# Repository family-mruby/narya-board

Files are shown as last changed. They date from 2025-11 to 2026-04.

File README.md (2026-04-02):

# Narya Board

A dual ESP32 development board featuring both ESP32-WROVER-IE and ESP32-S3-WROOM-1 modules on a single PCB.

## Overview

Narya Board is a versatile hardware platform that integrates two popular ESP32 variants, providing developers with flexibility for WiFi/Bluetooth applications, IoT prototyping, and embedded systems development.

## Features

- **Dual ESP32 Modules:**
  - ESP32-WROVER-IE (16MB Flash) - ESP32 classic with PSRAM
  - ESP32-S3-WROOM-1 (N16R8) - Latest ESP32-S3 with 16MB Flash and 8MB PSRAM
- **Video Output:** NTSC composite video output for retro gaming and multimedia applications
- **Audio Output:** Integrated audio output for sound and music playback
- **USB Host:** USB host interface for connecting peripherals
- **SD Card:** MicroSD card slot for external storage and data logging
- **GROVE Connector:** Standard GROVE connector for easy sensor and module integration
- **KiCad 9.0:** Designed with the latest KiCad EDA suite

## Hardware Specifications

## Block Diagram

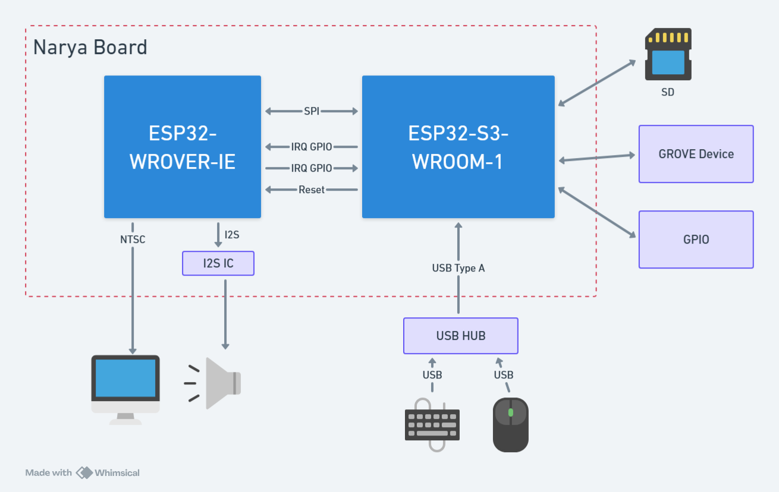
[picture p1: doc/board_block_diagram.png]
Block Diagram


### ESP32-WROVER-IE Module
- MCU: ESP32 Dual-core Xtensa LX6
- Flash: 16MB
- PSRAM: 8MB

### ESP32-S3-WROOM-1 Module
- MCU: ESP32-S3 Dual-core Xtensa LX7
- Flash: 16MB (N16)
- PSRAM: 8MB (R8)

## Project Structure

```
narya-board/
├── dev/
│   └── dev-board/              # Main KiCad project
│       ├── dev-board.kicad_pcb # PCB layout
│       ├── dev-board.kicad_sch # Main schematic
│       ├── dev-board.kicad_pro # KiCad project file
│       ├── S3_peripheral.kicad_sch        # ESP32-S3 peripheral circuits
│       ├── wrover_peripheral.kicad_sch   # WROVER peripheral circuits
│       ├── kicad/              # Custom libraries and footprints
│       └── production/         # Manufacturing files
│           ├── dev-board.zip   # Gerber files for fabrication
│           └── netlist.ipc     # IPC netlist
├── LICENSE
└── README.md
```

## History

### v3.0 dev R3

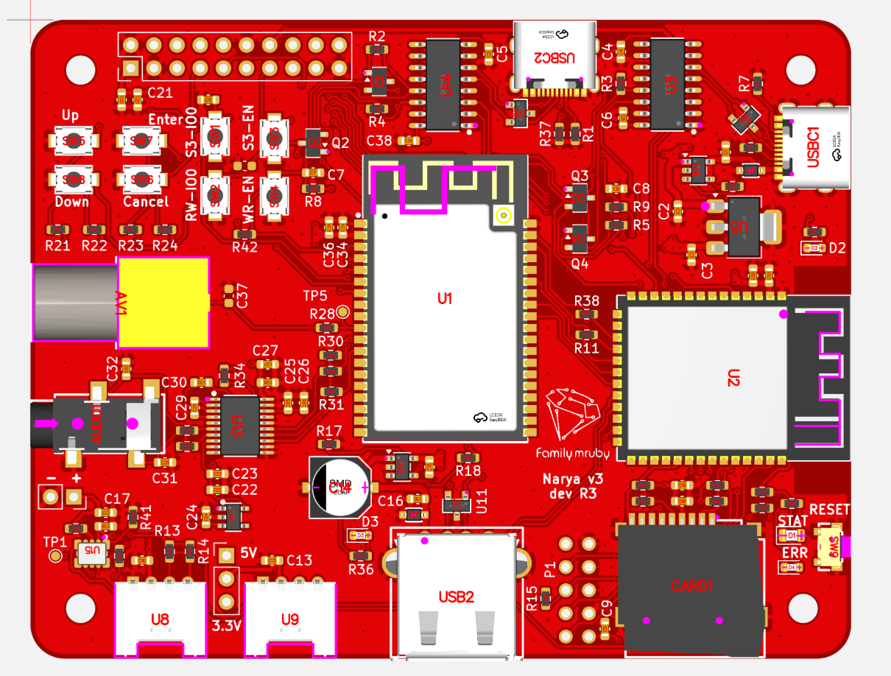
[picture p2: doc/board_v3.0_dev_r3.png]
3D Board View


## License

This project is licensed under the CERN-OHL-S - see the [LICENSE](LICENSE) file for details.

---

**Note:** This is a hardware development project. Ensure you have appropriate knowledge of electronics and safety precautions when working with these modules.

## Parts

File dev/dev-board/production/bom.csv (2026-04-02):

Designator | Footprint | Quantity | Value | LCSC Part #
AUDIO1 | AUDIO-SMD_PJ-327C-4A | 1 | PJ-327C-4A | C145813
AV1 | CONN-TH_AV-5 | 1 | AV-5 | C18080
C1, C10, C11, C13, C15, C16, C17, C18, C20, C23, C24, C25, C28, C33, C34, C38, C39, C4, C5, C6, C7, C8, C9 | 0603 | 23 | 0.1uF | C14663
C14 | CAP-SMD_BD6.3-L6.6-W6.6-LS7.2-R-RD | 1 | 120uF | C250087
C19, C2, C21, C22, C26, C27, C3 | 0603 | 7 | 10uF | C19702
C29, C30 | 0603 | 2 | 2.2uF | C23630
C31, C32 | 0603 | 2 | 2.2nF | C1604
C35, C36 | 0603 | 2 | 22uF | C84419
CARD1 | TF-SMD_TF-PUSH | 1 | TF PUSH | C393941
D1 | 0805 | 1 | LED GREEN | C2297
D2, D3, D4 | 0603 | 3 | LED RED | C2286
LDO1 | SOT-23-5_L3.0-W1.7-P0.95-LS2.8-BL | 1 | ME6211C33M5G-N | C82942
Q1, Q2, Q3, Q4 | SOT-23 | 4 | BSS138 | C82045
R1, R37, R6, R7 | 0603 | 4 | 5.1K | C23186
R10, R11, R12, R13, R14, R17, R18, R2, R20, R21, R22, R23, R24, R25, R26, R3, R34, R38, R4, R5, R8, R9 | 0603 | 22 | 10K | C25804
R15, R39, R40, R41, R42 | 0603 | 5 | 0 | C21189
R16, R19, R35, R36 | 0603 | 4 | 2K | C22975
R27, R28, R30, R31, R32 | 0603 | 5 | 22 | C23345
R29, R33 | 0603 | 2 | 470 | C23179
SW1, SW2, SW3, SW4, SW5, SW6, SW7, SW8 | KEY-SMD_L3.9-W3.0-LS5.0 | 8 | TS342A2P | C5373431
SW9 | SW-SMD_L4.7-W3.5-P3.35-EH | 1 | GT-TC018A-H0375-L1 | C963235
U1 | WIFI-SMD_ESP32-WROVER-IE8MB | 1 | ESP32-WROVER-IE(16MB) | C701352
U10, U4 | SOT-23-5 | 2 | TPS2065CDBV | C353882
U11, U16, U6 | SOT-23-3_L2.9-W1.3-P1.90-LS2.4-BR | 3 | PESD5V0U2BT | C2905622
U12, U7 | SOD-323_L1.7-W1.3-LS2.5-BI | 2 | PESD5V0S1BA_C5261083 | C5261083
U13 | TSSOP-20_L6.5-W4.4-P0.65-LS6.4-BL | 1 | PCM5102APWR | C107671
U14, U3 | SOP-16_L10.0-W3.9-P1.27-LS6.0-BL | 2 | CH340C | C84681
U15 | SMD-10_L3.2-W2.5-BL_EPSON_RX8900CE | 1 | RX8900CE_UB0 | C5903517
U2 | WIRELM-SMD_ESP32-S3-WROOM-1 | 1 | ESP32-S3-WROOM-1(N16R8) | C2913202
U5 | SOT-223-3_TabPin2 | 1 | AP7361C-33E | C150719
U8, U9 | CONN-TH_4P-P2.00_ZX-HY2.0-4PWZ | 2 | ZX-HY2.0-4PWZ | C7429589
USB2 | USB-A-TH_USB-231-ARY | 1 | USB-231-ARY | C720525
USBC1, USBC2 | USB-C_SMD-TYPE-C-31-M-12_1_Small | 2 | TYPE-C-31-M-12 | C165948

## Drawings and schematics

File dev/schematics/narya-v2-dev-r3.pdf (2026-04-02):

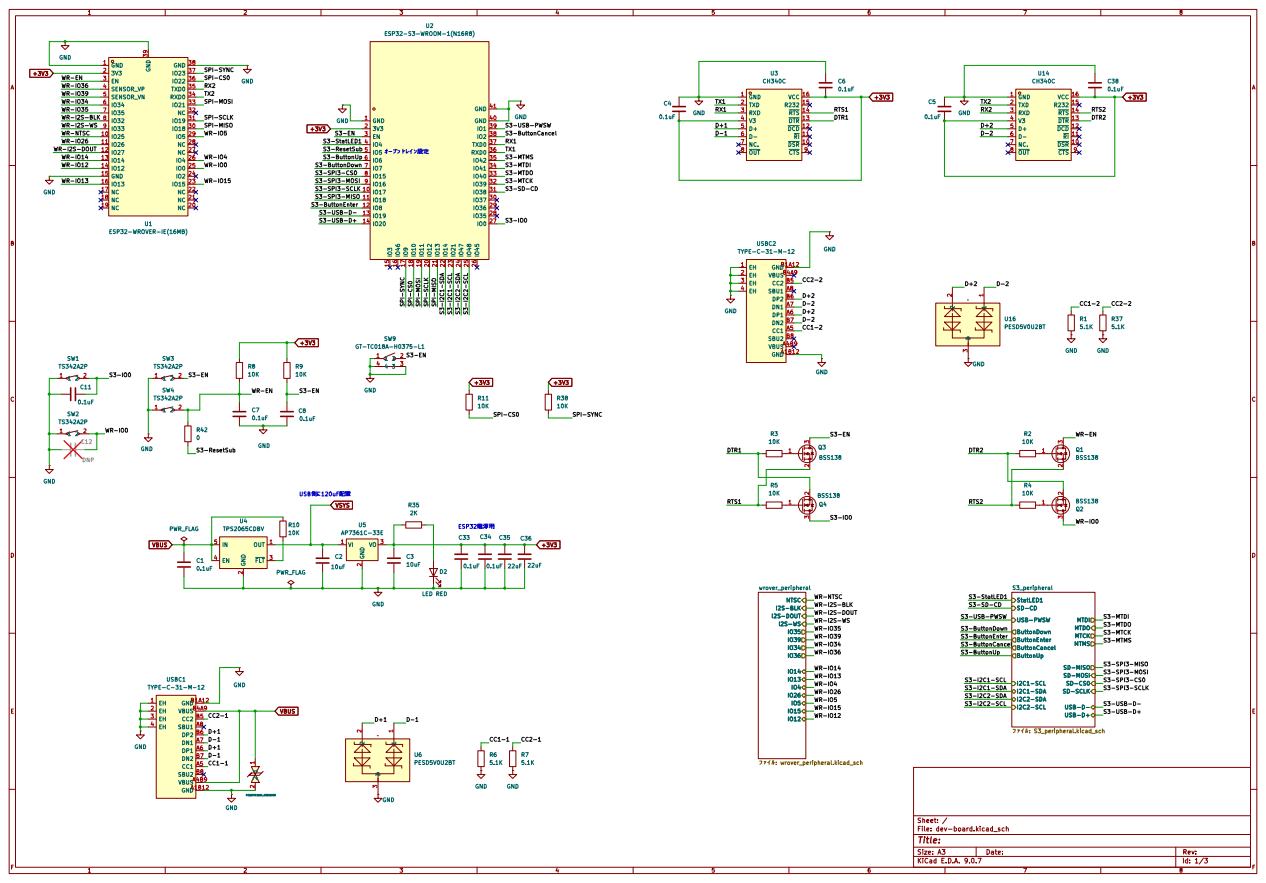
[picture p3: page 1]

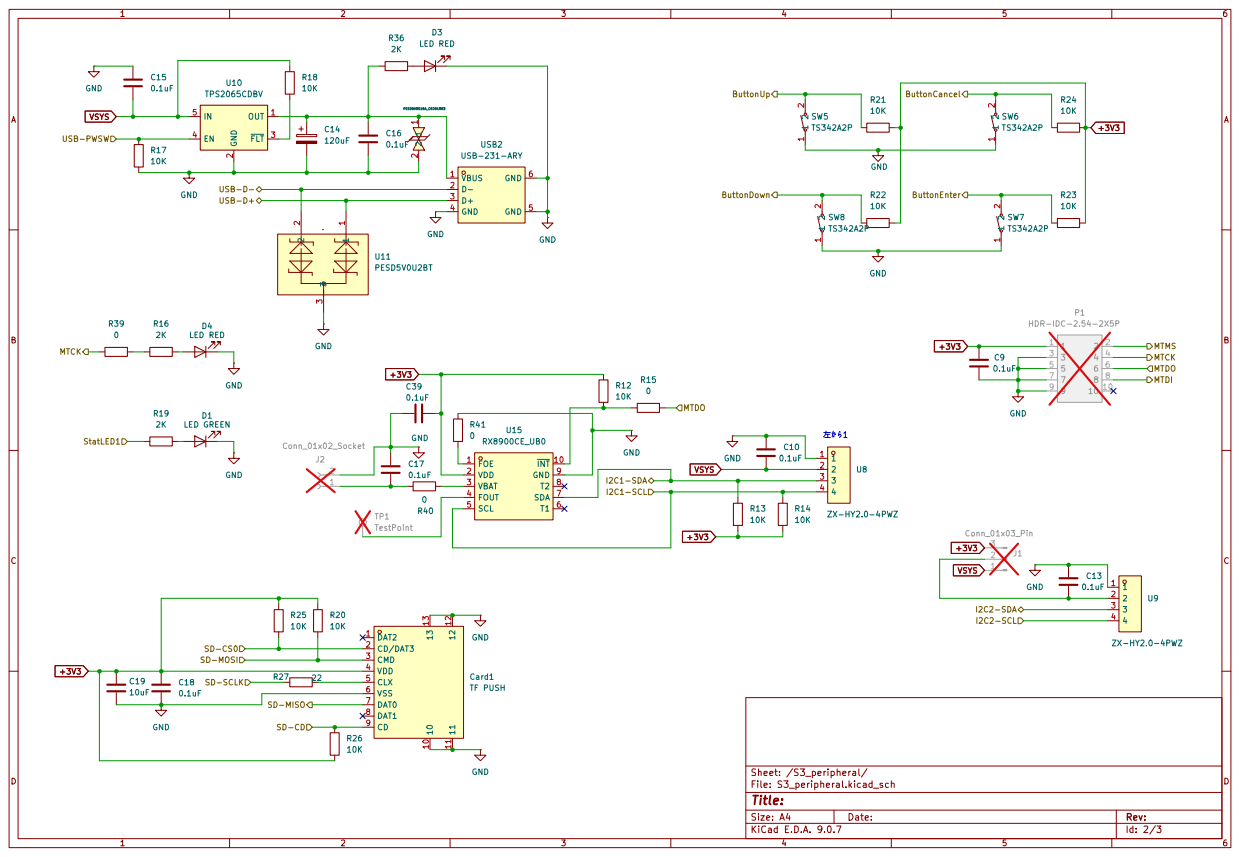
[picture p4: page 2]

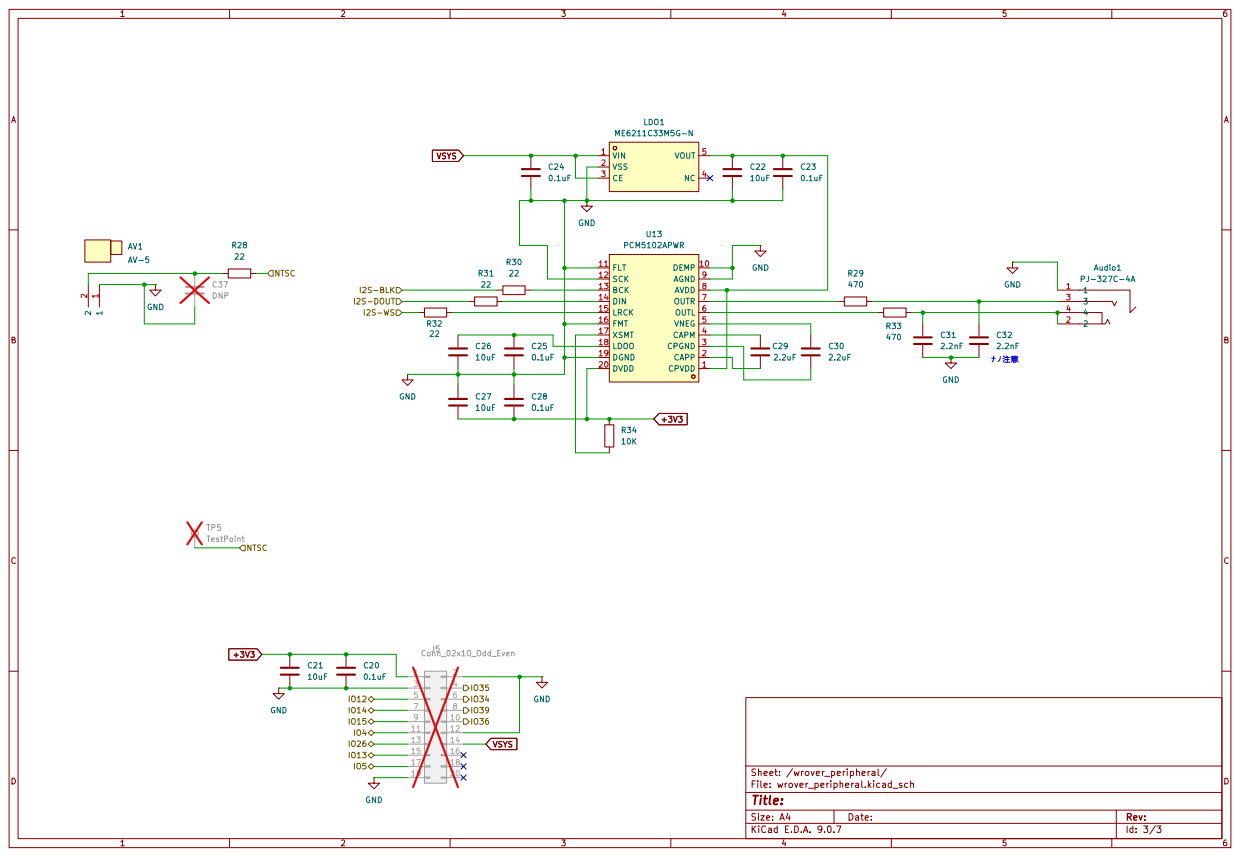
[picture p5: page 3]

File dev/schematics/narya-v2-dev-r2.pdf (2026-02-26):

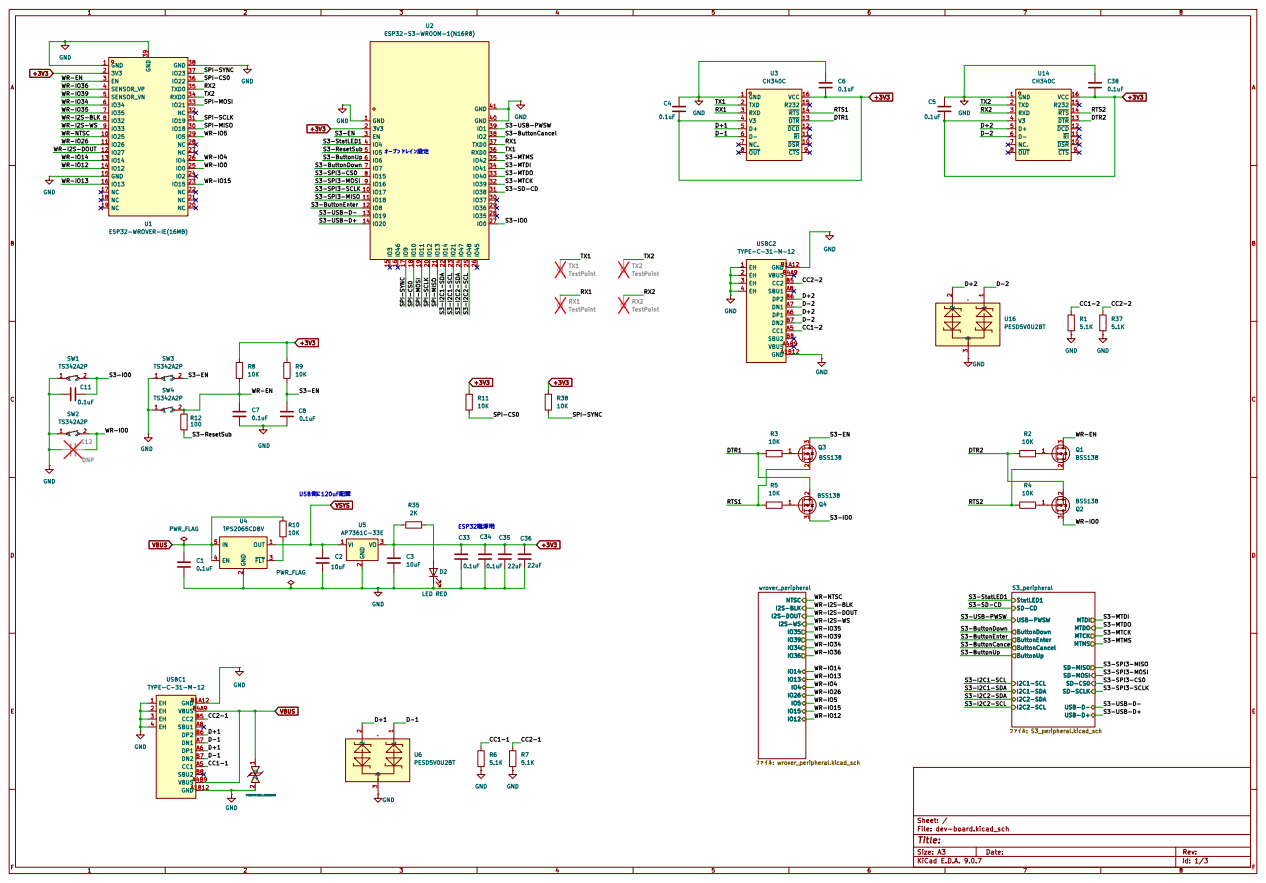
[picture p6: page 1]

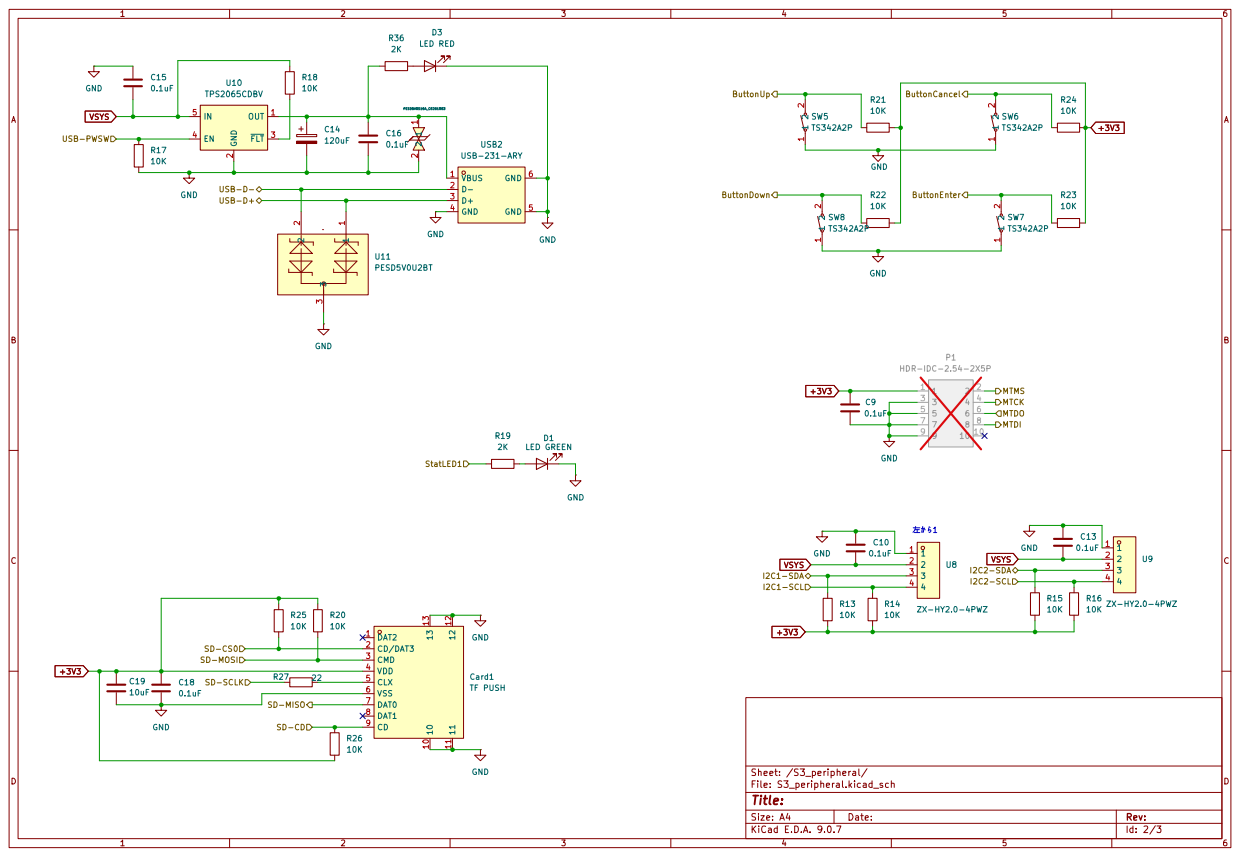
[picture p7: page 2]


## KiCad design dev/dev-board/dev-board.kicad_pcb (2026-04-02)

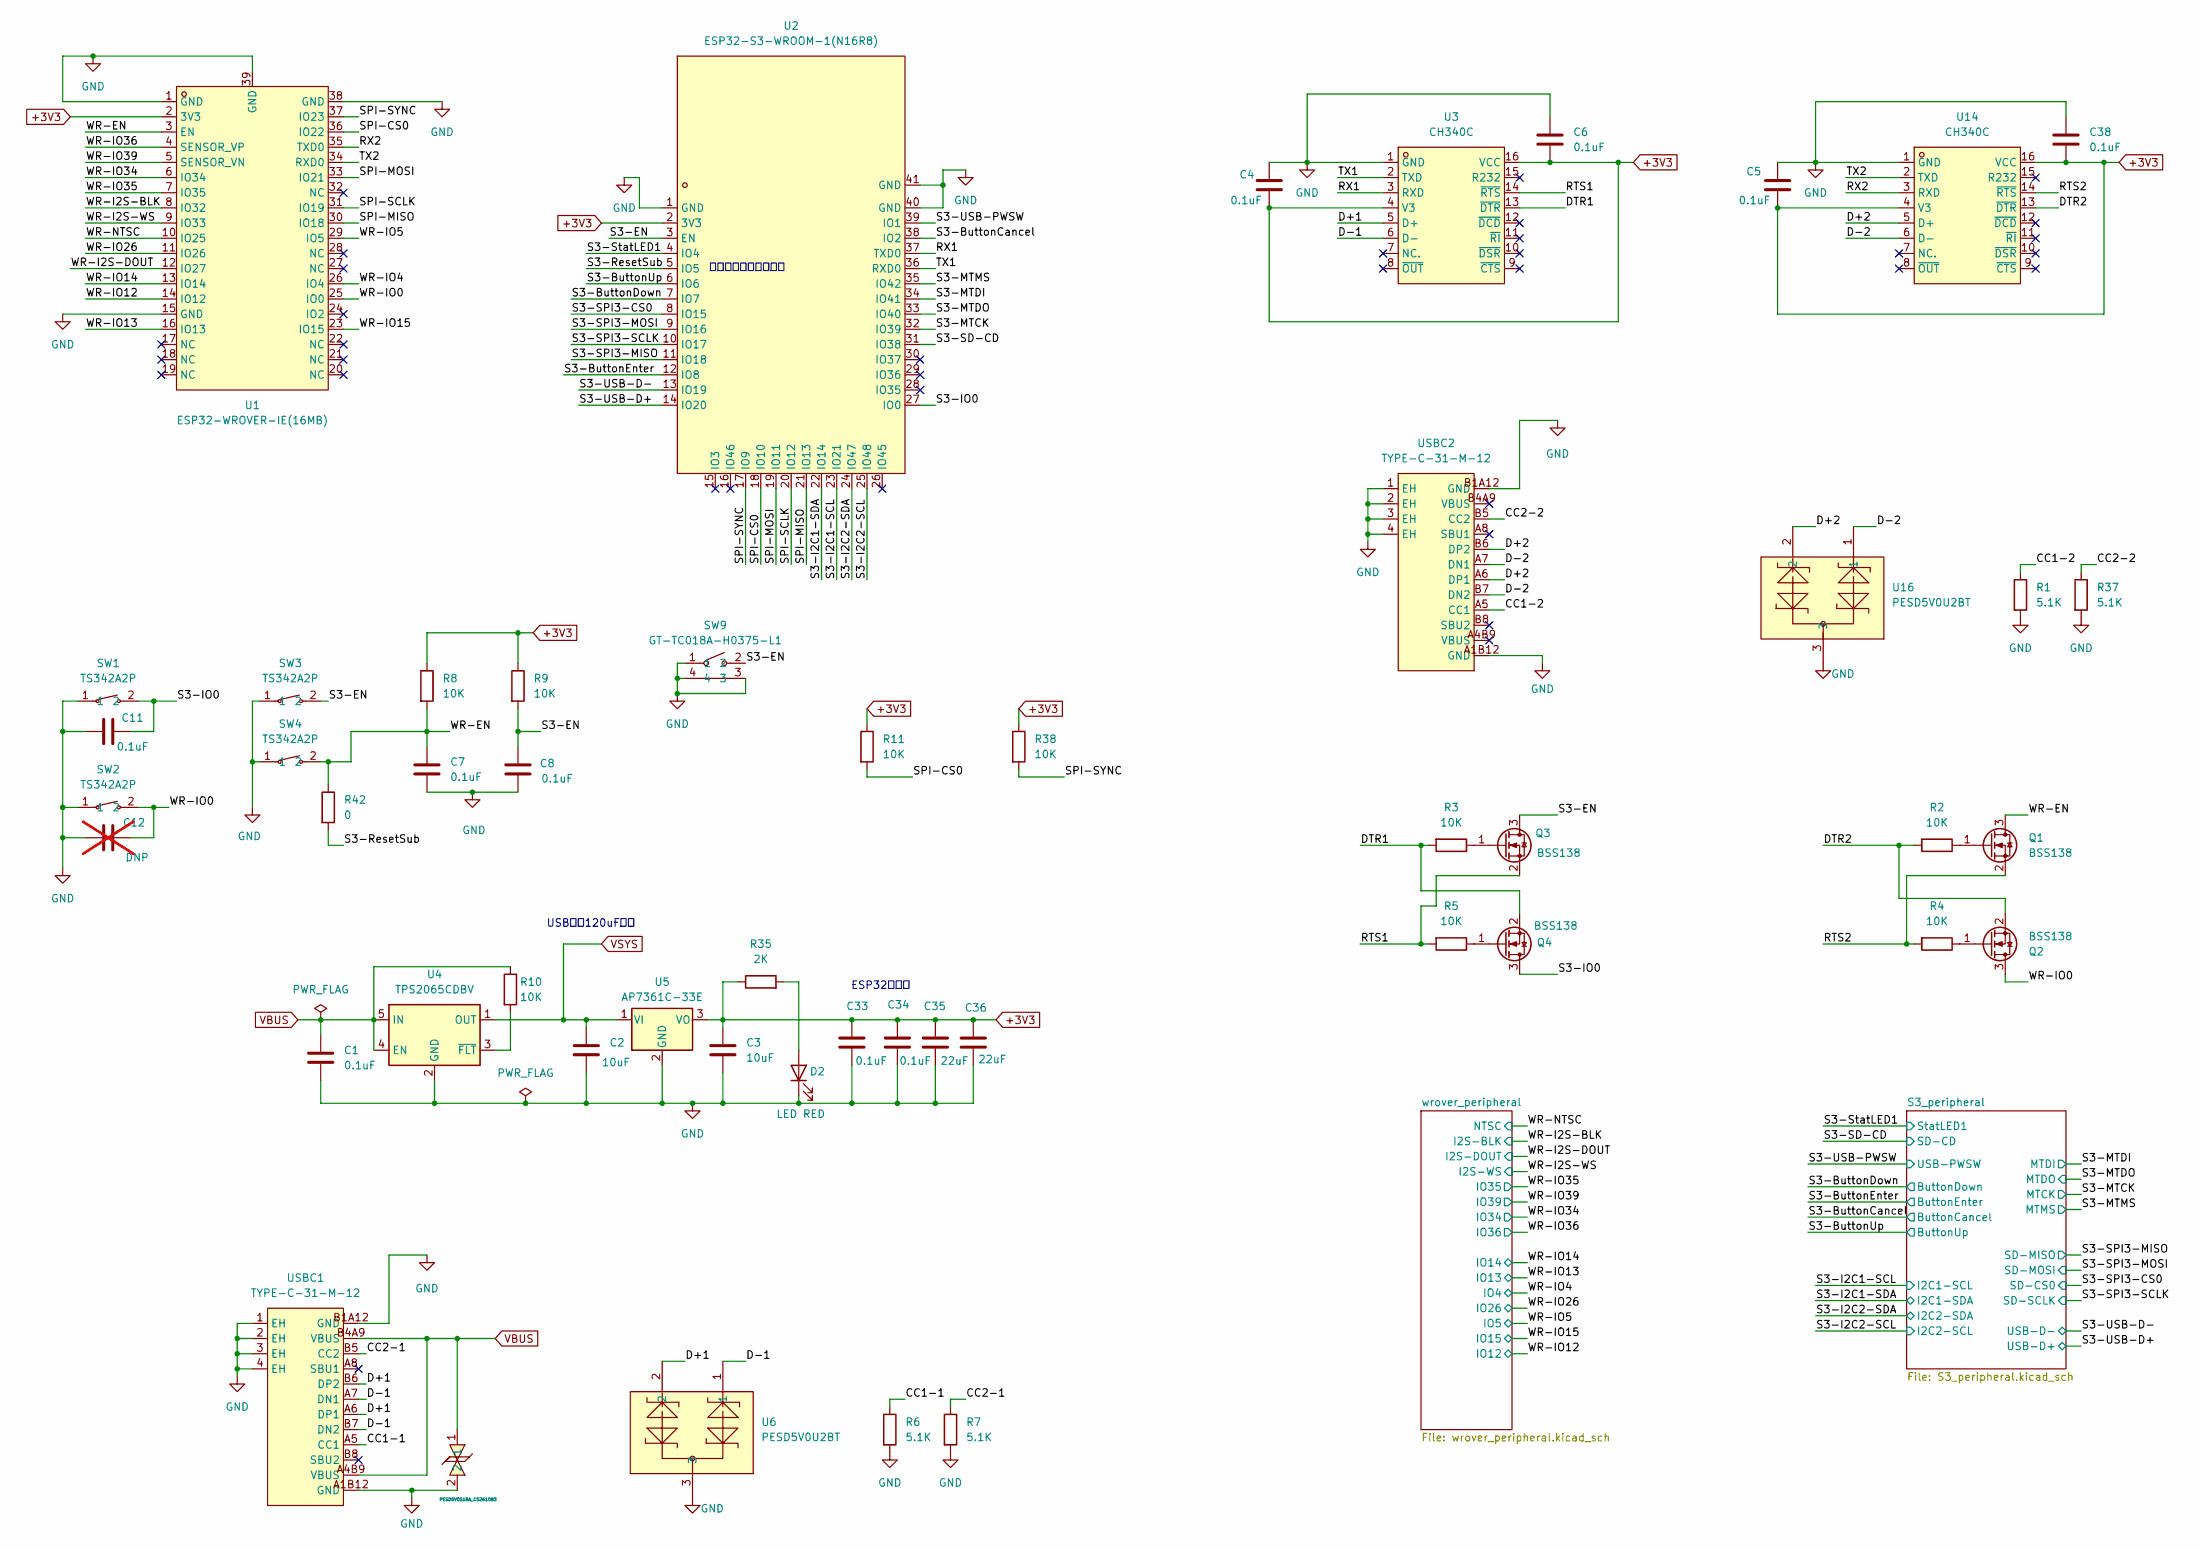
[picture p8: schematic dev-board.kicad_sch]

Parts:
C1, C4, C5, C6, C7, C8, C11, C33, C34, C38: 0.1uF; C_0603_1608Metric; LCSC Part C14663
C2, C3: 10uF; C_0603_1608Metric; LCSC Part C19702
C12: DNP; C_0603_1608Metric; not fitted
C35, C36: 22uF; C_0603_1608Metric; LCSC Part C84419
D2: LED RED; LED_0603_1608Metric; LCSC Part C2286
Q1, Q2, Q3, Q4: BSS138; SOT-23; LCSC Part C82045
R1, R6, R7, R37: 5.1K; R_0603_1608Metric; LCSC Part C23186
R2, R3, R4, R5, R8, R9, R10, R11, R38: 10K; R_0603_1608Metric; LCSC Part C25804
R35: 2K; R_0603_1608Metric; LCSC Part C22975
R42: 0; R_0603_1608Metric; LCSC Part C21189
SW1, SW2, SW3, SW4: TS342A2P; KEY-SMD_L3.9-W3.0-LS5.0; LCSC Part C5373431
SW9: GT-TC018A-H0375-L1; SW-SMD_L4.7-W3.5-P3.35-EH; LCSC Part C963235
U1: ESP32-WROVER-IE(16MB); WIFI-SMD_ESP32-WROVER-IE8MB; LCSC Part C701352
U2: ESP32-S3-WROOM-1(N16R8); WIRELM-SMD_ESP32-S3-WROOM-1; LCSC Part C2913202
U3, U14: CH340C; SOP-16_L10.0-W3.9-P1.27-LS6.0-BL; LCSC Part C84681
U4: TPS2065CDBV; SOT-23-5; LCSC Part C353882
U5: AP7361C-33E; SOT-223-3_TabPin2; LCSC Part C150719
U6, U16: PESD5V0U2BT; SOT-23-3_L2.9-W1.3-P1.90-LS2.4-BR; LCSC Part C2905622
U7: PESD5V0S1BA_C5261083; SOD-323_L1.7-W1.3-LS2.5-BI; LCSC Part C5261083
USBC1, USBC2: TYPE-C-31-M-12; USB-C_SMD-TYPE-C-31-M-12_1_Small; LCSC Part C165948

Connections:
+3V3: C3.1, C4.2, C5.2, C6.2, C33.1, C34.1, C35.1, C36.1, C38.2, R8.1, R9.1, R11.1, R35.1, R38.1, U1.2 (3V3), U2.2 (3V3), U3.4 (V3), U3.16 (VCC), U5.3 (VO), U14.4 (V3), U14.16 (VCC); also elsewhere on the board
/CC1-1: R6.1, USBC1.A5 (CC1)
/CC1-2: R1.1, USBC2.A5 (CC1)
/CC2-1: R7.1, USBC1.B5 (CC2)
/CC2-2: R37.1, USBC2.B5 (CC2)
/D+1: U3.5 (D+), U6.2, USBC1.A6 (DP1), USBC1.B6 (DP2)
/D+2: U14.5 (D+), U16.2, USBC2.A6 (DP1), USBC2.B6 (DP2)
/D-1: U3.6 (D-), U6.1, USBC1.A7 (DN1), USBC1.B7 (DN2)
/D-2: U14.6 (D-), U16.1, USBC2.A7 (DN1), USBC2.B7 (DN2)
/DTR1: Q4.2 (S), R3.2, U3.13 (~DTR)
/DTR2: Q2.2 (S), R2.2, U14.13 (~DTR)
/RTS1: Q3.2 (S), R5.2, U3.14 (~RTS)
/RTS2: Q1.2 (S), R4.2, U14.14 (~RTS)
/RX1: U2.37 (TXD0), U3.3 (RXD)
/RX2: U1.35 (TXD0), U14.3 (RXD)
/S3-ButtonCancel: U2.38 (IO2); also elsewhere on the board
/S3-ButtonDown: U2.7 (IO7); also elsewhere on the board
/S3-ButtonEnter: U2.12 (IO8); also elsewhere on the board
/S3-ButtonUp: U2.6 (IO6); also elsewhere on the board
/S3-EN: C8.1, Q3.3 (D), R9.2, SW3.2, SW9.2, U2.3 (EN)
/S3-I2C1-SCL: U2.23 (IO21); also elsewhere on the board
/S3-I2C1-SDA: U2.22 (IO14); also elsewhere on the board
/S3-I2C2-SCL: U2.25 (IO48); also elsewhere on the board
/S3-I2C2-SDA: U2.24 (IO47); also elsewhere on the board
/S3-IO0: C11.2, Q4.3 (D), SW1.2, U2.27 (IO0)
/S3-MTCK: U2.32 (IO39); also elsewhere on the board
/S3-MTDI: U2.34 (IO41); also elsewhere on the board
/S3-MTDO: U2.33 (IO40); also elsewhere on the board
/S3-MTMS: U2.35 (IO42); also elsewhere on the board
/S3-ResetSub: R42.2, U2.5 (IO5)
/S3-SD-CD: U2.31 (IO38); also elsewhere on the board
/S3-SPI3-CS0: U2.8 (IO15); also elsewhere on the board
/S3-SPI3-MISO: U2.11 (IO18); also elsewhere on the board
/S3-SPI3-MOSI: U2.9 (IO16); also elsewhere on the board
/S3-SPI3-SCLK: U2.10 (IO17); also elsewhere on the board
/S3-StatLED1: U2.4 (IO4); also elsewhere on the board
/S3-USB-D+: U2.14 (IO20); also elsewhere on the board
/S3-USB-D-: U2.13 (IO19); also elsewhere on the board
/S3-USB-PWSW: U2.39 (IO1); also elsewhere on the board
/SPI-CS0: R11.2, U1.36 (IO22), U2.18 (IO10)
/SPI-MISO: U1.30 (IO18), U2.21 (IO13)
/SPI-MOSI: U1.33 (IO21), U2.19 (IO11)
/SPI-SCLK: U1.31 (IO19), U2.20 (IO12)
/SPI-SYNC: R38.2, U1.37 (IO23), U2.17 (IO9)
/TX1: U2.36 (RXD0), U3.2 (TXD)
/TX2: U1.34 (RXD0), U14.2 (TXD)
/WR-EN: C7.1, Q1.3 (D), R8.2, R42.1, SW4.2, U1.3 (EN)
/WR-I2S-BLK: U1.8 (IO32); also elsewhere on the board
/WR-I2S-DOUT: U1.12 (IO27); also elsewhere on the board
/WR-I2S-WS: U1.9 (IO33); also elsewhere on the board
/WR-IO0: C12.2, Q2.3 (D), SW2.2, U1.25 (IO0)
/WR-IO4: U1.26 (IO4); also elsewhere on the board
/WR-IO5: U1.29 (IO5); also elsewhere on the board
/WR-IO12: U1.14 (IO12); also elsewhere on the board
/WR-IO13: U1.16 (IO13); also elsewhere on the board
/WR-IO14: U1.13 (IO14); also elsewhere on the board
/WR-IO15: U1.23 (IO15); also elsewhere on the board
/WR-IO26: U1.11 (IO26); also elsewhere on the board
/WR-IO34: U1.6 (IO34); also elsewhere on the board
/WR-IO35: U1.7 (IO35); also elsewhere on the board
/WR-IO36: U1.4 (SENSOR_VP); also elsewhere on the board
/WR-IO39: U1.5 (SENSOR_VN); also elsewhere on the board
/WR-NTSC: U1.10 (IO25); also elsewhere on the board
GND: C1.2, C2.2, C3.2, C4.1, C5.1, C6.1, C7.2, C8.2, C11.1, C12.1, C33.2, C34.2, C35.2, C36.2, C38.1, D2.1 (K), R1.2, R6.2, R7.2, R37.2, SW1.1, SW2.1, SW3.1, SW4.1, SW9.1, SW9.3, SW9.4, U1.1 (GND), U1.15 (GND), U1.38 (GND), U1.39 (GND), U2.1 (GND), U2.40 (GND), U2.41 (GND), U3.1 (GND), U4.2 (GND), U5.2 (GND), U6.3, U7.2, U14.1 (GND), U16.3, USBC1.1 (EH), USBC1.2 (EH), USBC1.3 (EH), USBC1.4 (EH), USBC1.A1B12 (GND), USBC1.B1A12 (GND), USBC2.1 (EH), USBC2.2 (EH), USBC2.3 (EH), USBC2.4 (EH), USBC2.A1B12 (GND), USBC2.B1A12 (GND); also elsewhere on the board
unnamed: D2.2 (A), R35.2
unnamed: Q1.1 (G), R2.1
unnamed: Q2.1 (G), R4.1
unnamed: Q3.1 (G), R3.1
unnamed: Q4.1 (G), R5.1
unnamed: R10.2, U4.3 (~FLT)
VBUS: C1.1, R10.1, U4.4 (EN), U4.5 (IN), U7.1, USBC1.A4B9 (VBUS), USBC1.B4A9 (VBUS)
VSYS: C2.1, U4.1 (OUT), U5.1 (VI); also elsewhere on the board

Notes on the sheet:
ESP32電源用
オープンドレイン設定
USB側に120uF配置

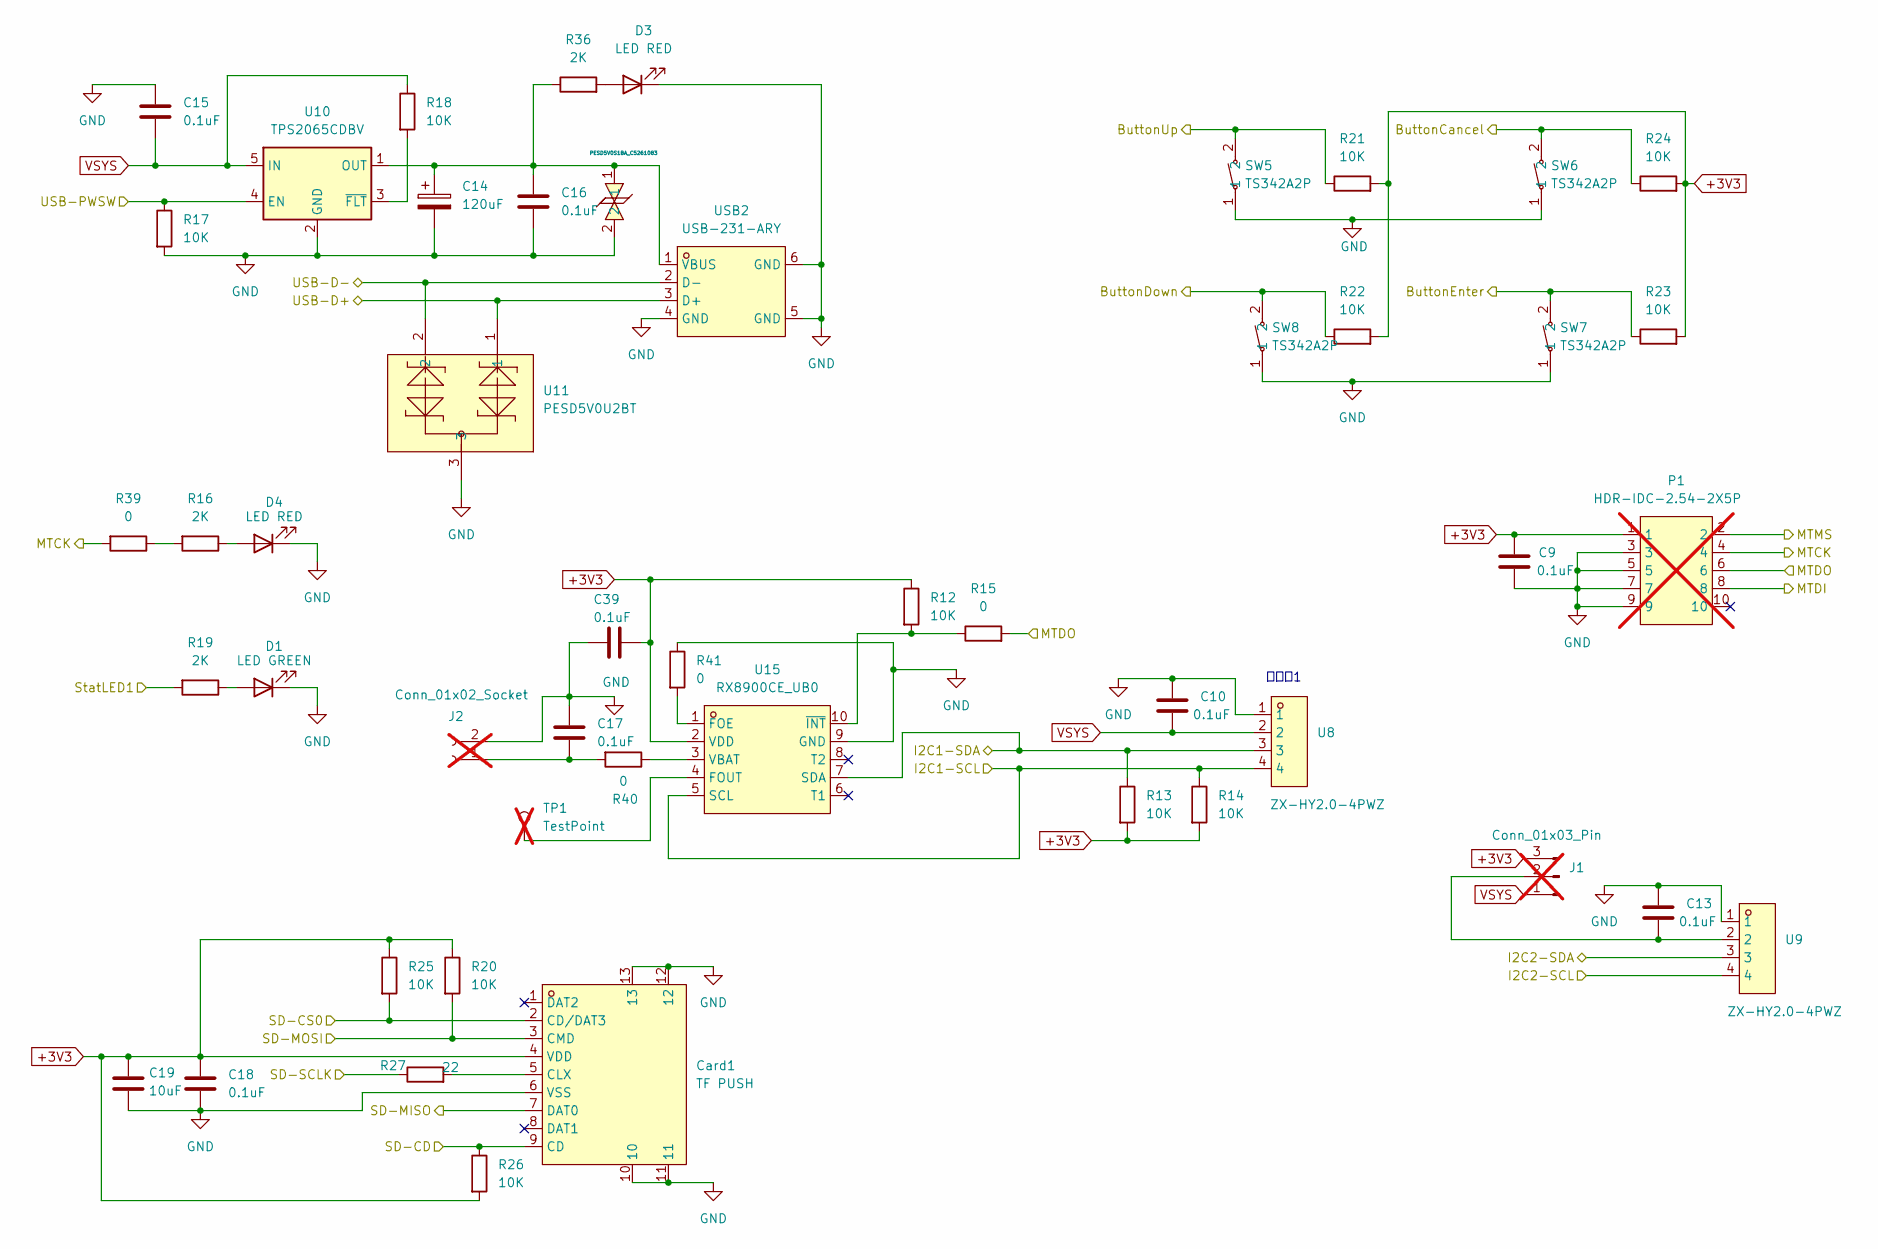
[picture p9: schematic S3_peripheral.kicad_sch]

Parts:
C9, C10, C13, C15, C16, C17, C18, C39: 0.1uF; C_0603_1608Metric; LCSC Part C14663
C14: 120uF; CAP-SMD_BD6.3-L6.6-W6.6-LS7.2-R-RD; LCSC Part C250087
C19: 10uF; C_0603_1608Metric; LCSC Part C19702
Card1: TF PUSH; TF-SMD_TF-PUSH; LCSC Part C393941
D1: LED GREEN; LED_0805_2012Metric; LCSC Part C2297
D3, D4: LED RED; LED_0603_1608Metric; LCSC Part C2286
J1: Conn_01x03_Pin; PinHeader_1x03_P2.54mm_Vertical; not fitted
J2: Conn_01x02_Socket; PinSocket_1x02_P2.54mm_Vertical; not fitted
P1: HDR-IDC-2.54-2X5P; IDC-TH_10P-P2.54_C5665; LCSC Part C5665; not fitted
R12, R13, R14, R17, R18, R20, R21, R22, R23, R24, R25, R26: 10K; R_0603_1608Metric; LCSC Part C25804
R15, R39, R40, R41: 0; R_0603_1608Metric; LCSC Part C21189
R16, R19, R36: 2K; R_0603_1608Metric; LCSC Part C22975
R27: 22; R_0603_1608Metric; LCSC Part C23345
SW5, SW6, SW7, SW8: TS342A2P; KEY-SMD_L3.9-W3.0-LS5.0; LCSC Part C5373431
TP1: TestPoint; TestPoint_Pad_D1.0mm; not fitted
U8, U9: ZX-HY2.0-4PWZ; CONN-TH_4P-P2.00_ZX-HY2.0-4PWZ; LCSC Part C7429589
U10: TPS2065CDBV; SOT-23-5; LCSC Part C353882
U11: PESD5V0U2BT; SOT-23-3_L2.9-W1.3-P1.90-LS2.4-BR; LCSC Part C2905622
U12: PESD5V0S1BA_C5261083; SOD-323_L1.7-W1.3-LS2.5-BI; LCSC Part C5261083
U15: RX8900CE_UB0; SMD-10_L3.2-W2.5-BL_EPSON_RX8900CE; LCSC Part C5903517
USB2: USB-231-ARY; USB-A-TH_USB-231-ARY; LCSC Part C720525

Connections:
+3V3: C9.1, C18.1, C19.1, C39.2, Card1.4 (VDD), J1.3, P1.1, R12.1, R13.2, R14.2, R20.1, R21.2, R22.2, R23.2, R24.2, R25.1, R26.2, U15.2 (VDD); also elsewhere on the board
/S3-ButtonCancel: R24.1, SW6.2; also elsewhere on the board
/S3-ButtonDown: R22.1, SW8.2; also elsewhere on the board
/S3-ButtonEnter: R23.1, SW7.2; also elsewhere on the board
/S3-ButtonUp: R21.1, SW5.2; also elsewhere on the board
/S3-I2C1-SCL: R14.1, U8.4, U15.5 (SCL); also elsewhere on the board
/S3-I2C1-SDA: R13.1, U8.3, U15.7 (SDA); also elsewhere on the board
/S3-I2C2-SCL: U9.4; also elsewhere on the board
/S3-I2C2-SDA: U9.3; also elsewhere on the board
/S3-MTCK: P1.4, R39.2; also elsewhere on the board
/S3-MTDI: P1.8; also elsewhere on the board
/S3-MTDO: P1.6, R15.2; also elsewhere on the board
/S3-MTMS: P1.2; also elsewhere on the board
/S3-SD-CD: Card1.9 (CD), R26.1; also elsewhere on the board
/S3-SPI3-CS0: Card1.2 (CD/DAT3), R25.2; also elsewhere on the board
/S3-SPI3-MISO: Card1.7 (DAT0); also elsewhere on the board
/S3-SPI3-MOSI: Card1.3 (CMD), R20.2; also elsewhere on the board
/S3-SPI3-SCLK: R27.1; also elsewhere on the board
/S3-StatLED1: R19.2; also elsewhere on the board
/S3-USB-D+: U11.1, USB2.3 (D+); also elsewhere on the board
/S3-USB-D-: U11.2, USB2.2 (D-); also elsewhere on the board
/S3-USB-PWSW: R17.1, U10.4 (EN); also elsewhere on the board
GND: C9.2, C10.1, C13.1, C14.2, C15.1, C16.2, C17.1, C18.2, C19.2, C39.1, Card1.6 (VSS), Card1.10, Card1.11, Card1.12, Card1.13, D1.1 (K), D3.1 (K), D4.1 (K), J2.2, P1.3, P1.5, P1.7, P1.9, R17.2, R41.1, SW5.1, SW6.1, SW7.1, SW8.1, U8.1, U9.1, U10.2 (GND), U11.3, U12.2, U15.9 (GND), USB2.4 (GND), USB2.5 (GND), USB2.6 (GND); also elsewhere on the board
unnamed: Card1.5 (CLX), R27.2
unnamed: D1.2 (A), R19.1
unnamed: D3.2 (A), R36.2
unnamed: D4.2 (A), R16.1
unnamed: C13.2, J1.2, U9.2
unnamed: C17.2, J2.1, R40.2
unnamed: R16.2, R39.1
unnamed: C14.1, C16.1, R36.1, U10.1 (OUT), U12.1, USB2.1 (VBUS)
unnamed: R18.2, U10.3 (~FLT)
unnamed: R41.2, U15.1 (FOE)
unnamed: TP1.1, U15.4 (FOUT)
unnamed: R40.1, U15.3 (VBAT)
unnamed: R12.2, R15.1, U15.10 (~INT)
VSYS: C10.2, C15.2, J1.1, R18.1, U8.2, U10.5 (IN); also elsewhere on the board

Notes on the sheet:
左から1

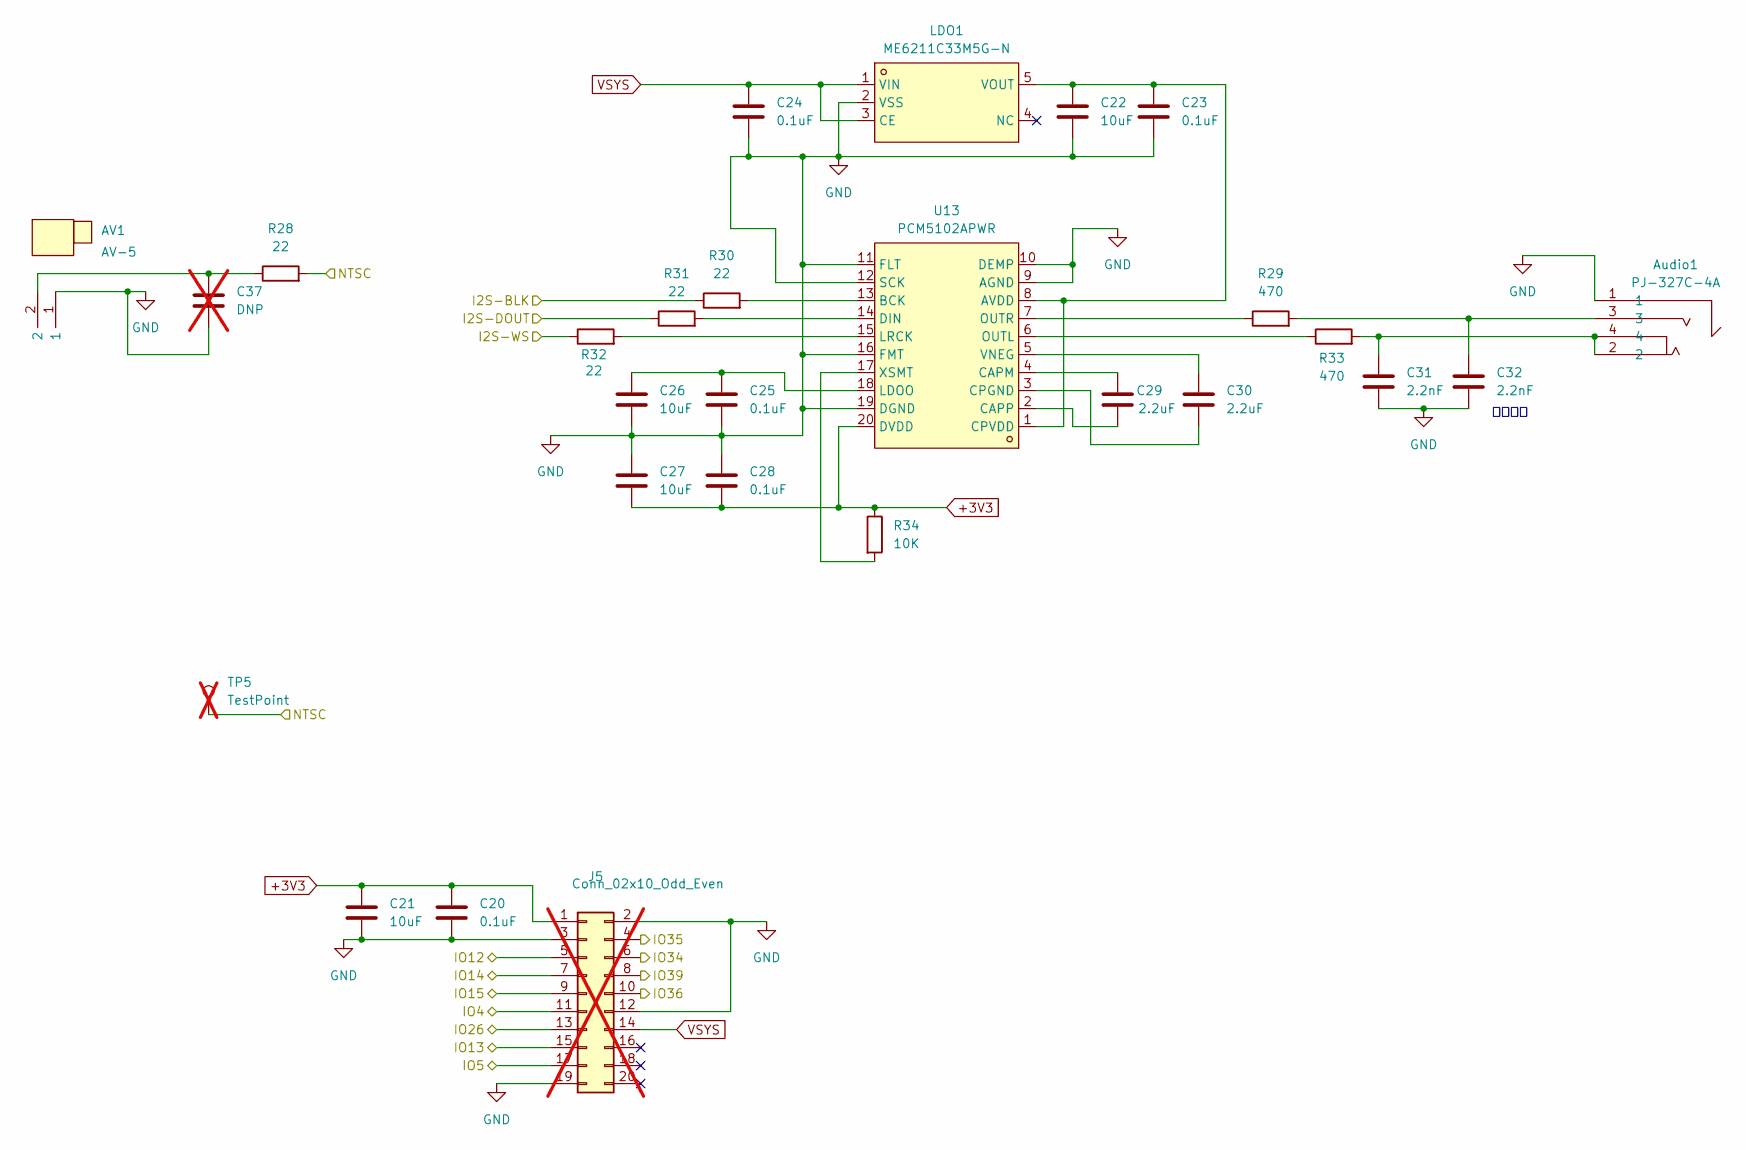
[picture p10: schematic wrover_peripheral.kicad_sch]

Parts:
AV1: AV-5; CONN-TH_AV-5; LCSC Part C18080
Audio1: PJ-327C-4A; AUDIO-SMD_PJ-327C-4A; LCSC Part C145813
C20, C23, C24, C25, C28: 0.1uF; C_0603_1608Metric; LCSC Part C14663
C21, C22, C26, C27: 10uF; C_0603_1608Metric; LCSC Part C19702
C29, C30: 2.2uF; C_0603_1608Metric; LCSC Part C23630
C31, C32: 2.2nF; C_0603_1608Metric; LCSC Part C1604
C37: DNP; C_0603_1608Metric; not fitted
J5: Conn_02x10_Odd_Even; PinHeader_2x10_P2.54mm_Vertical; not fitted
LDO1: ME6211C33M5G-N; SOT-23-5_L3.0-W1.7-P0.95-LS2.8-BL; LCSC Part C82942
R28, R30, R31, R32: 22; R_0603_1608Metric; LCSC Part C23345
R29, R33: 470; R_0603_1608Metric; LCSC Part C23179
R34: 10K; R_0603_1608Metric; LCSC Part C25804
TP5: TestPoint; TestPoint_Pad_D1.0mm; not fitted
U13: PCM5102APWR; TSSOP-20_L6.5-W4.4-P0.65-LS6.4-BL; LCSC Part C107671

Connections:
+3V3: C20.1, C21.1, C27.2, C28.2, J5.1, R34.1, U13.20 (DVDD); also elsewhere on the board
/WR-I2S-BLK: R30.1; also elsewhere on the board
/WR-I2S-DOUT: R31.1; also elsewhere on the board
/WR-I2S-WS: R32.1; also elsewhere on the board
/WR-IO4: J5.11; also elsewhere on the board
/WR-IO5: J5.17; also elsewhere on the board
/WR-IO12: J5.5; also elsewhere on the board
/WR-IO13: J5.15; also elsewhere on the board
/WR-IO14: J5.7; also elsewhere on the board
/WR-IO15: J5.9; also elsewhere on the board
/WR-IO26: J5.13; also elsewhere on the board
/WR-IO34: J5.6; also elsewhere on the board
/WR-IO35: J5.4; also elsewhere on the board
/WR-IO36: J5.10; also elsewhere on the board
/WR-IO39: J5.8; also elsewhere on the board
/WR-NTSC: R28.2, TP5.1; also elsewhere on the board
GND: AV1.1, Audio1.1, C20.2, C21.2, C22.2, C23.2, C24.2, C25.2, C26.2, C27.1, C28.1, C31.2, C32.2, C37.2, J5.2, J5.3, J5.12, J5.19, LDO1.2 (VSS), U13.9 (AGND), U13.10 (DEMP), U13.11 (FLT), U13.12 (SCK), U13.16 (FMT), U13.19 (DGND); also elsewhere on the board
unnamed: AV1.2, C37.1, R28.1
unnamed: Audio1.2, Audio1.4, C31.1, R33.2
unnamed: Audio1.3, C32.1, R29.2
unnamed: C22.1, C23.1, LDO1.5 (VOUT), U13.1 (CPVDD), U13.8 (AVDD)
unnamed: R30.2, U13.13 (BCK)
unnamed: C29.1, U13.4 (CAPM)
unnamed: C29.2, U13.2 (CAPP)
unnamed: C30.2, U13.3 (CPGND)
unnamed: R31.2, U13.14 (DIN)
unnamed: C25.1, C26.1, U13.18 (LDOO)
unnamed: R32.2, U13.15 (LRCK)
unnamed: R33.1, U13.6 (OUTL)
unnamed: R29.1, U13.7 (OUTR)
unnamed: C30.1, U13.5 (VNEG)
unnamed: R34.2, U13.17 (XSMT)
VSYS: C24.1, J5.14, LDO1.1 (VIN), LDO1.3 (CE); also elsewhere on the board

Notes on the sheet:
ナノ注意

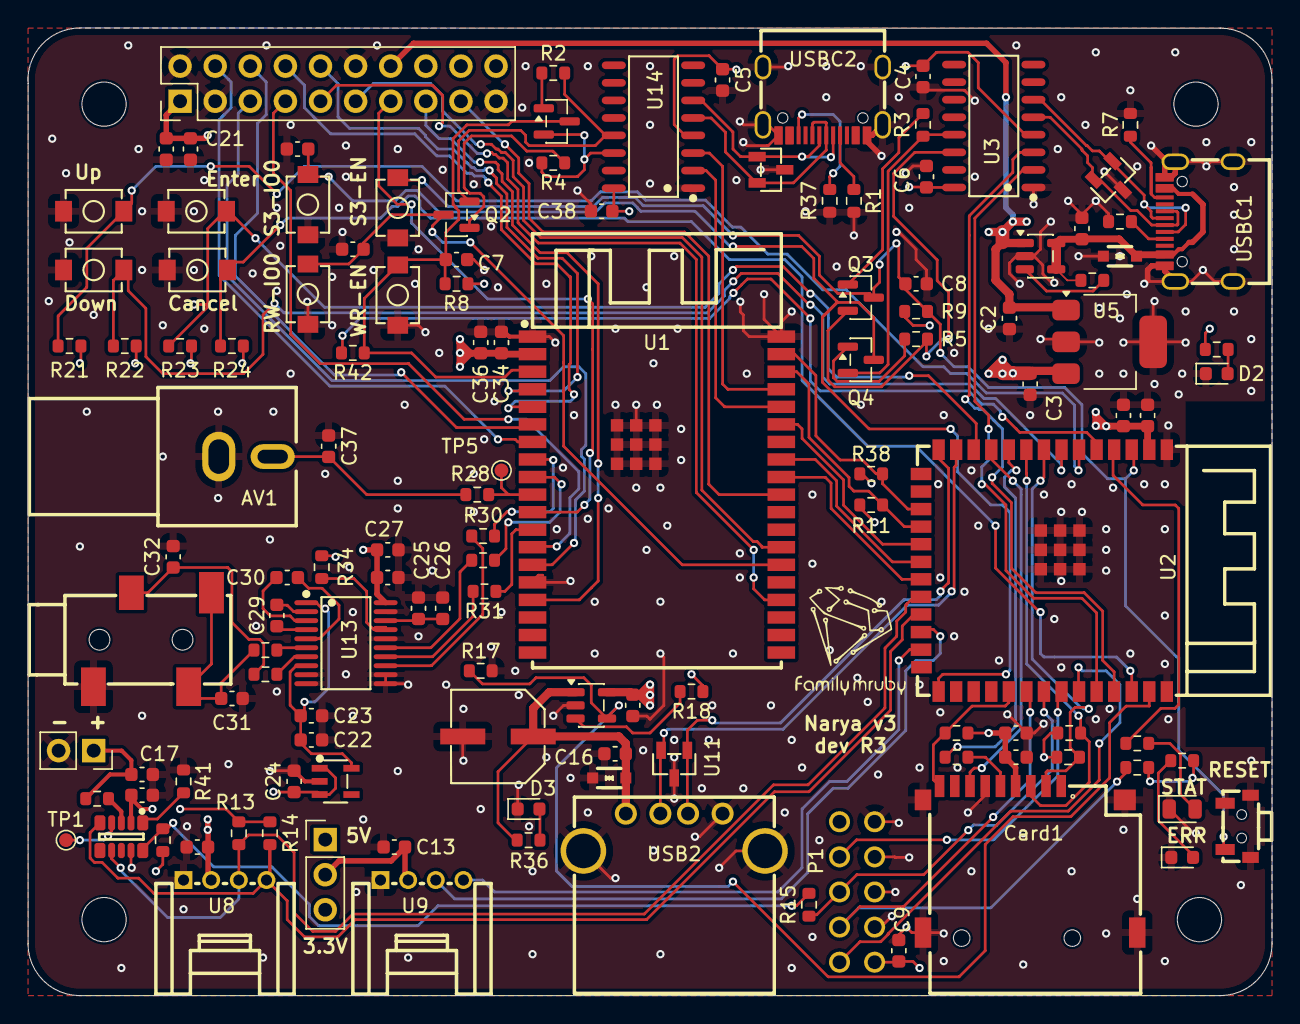
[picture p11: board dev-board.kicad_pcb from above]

Board: 4 copper layers, 90.0 x 70.0 mm, 131 parts (0 on the bottom side), 100 nets.

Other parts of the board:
REF1, REF2, REF3, REF4: MountingHole_3.2mm_M3

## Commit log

2025-10-02 add kicad files
    [S3_peripheral.kicad_sch, dev-board.kicad_pcb, dev-board.kicad_sch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]
2025-10-08 making CAD
    [S3_peripheral.kicad_sch, dev-board.kicad_pcb, dev-board.kicad_sch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]
2025-10-11 finish cad. 1st step. add symbol,footprint files
    [S3_peripheral.kicad_sch, dev-board.kicad_pcb, dev-board.kicad_sch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]
2025-10-11 complete BOM
    [S3_peripheral.kicad_sch, dev-board.kicad_pcb, dev-board.kicad_sch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]
2025-10-11 change board size. change C14
    [S3_peripheral.kicad_sch, dev-board.kicad_pcb]
2025-11-05 fix LCSC num, improve cad
    [S3_peripheral.kicad_sch, dev-board.kicad_pcb, dev-board.kicad_sch]
2025-11-11 release candidadte
    [dev-board.kicad_pcb]
2026-02-22 update schematics
    [S3_peripheral.kicad_sch, dev-board.kicad_sch, wrover_peripheral.kicad_sch]
2026-02-22 designing R2 board
    [dev-board-r1.kicad_pcb, dev-board.kicad_pcb]
2026-02-23 wiring donw. checking DRC
    [dev-board.kicad_pcb, wrover_peripheral.kicad_sch]
2026-02-23 checking before release
    [dev-board.kicad_pcb]
2026-02-24 r2 candidate
    [dev-board.kicad_pcb, dev-board.kicad_sch, wrover_peripheral.kicad_sch]
2026-02-24 r2 candidate (fix CH340 V3-VCC)
    [dev-board.kicad_pcb, dev-board.kicad_sch]
2026-02-24 r2 candidate (fix silk, add via around ESP32 GND pad)
    [dev-board.kicad_pcb]
2026-02-26 add schematics of v2-dev-r2
2026-02-28 add bom.csv and positions.csv for production
    [bom.csv, positions.csv]
2026-03-29 update for v3r3
    [S3_peripheral.kicad_sch, dev-board-r2.kicad_pcb, dev-board.kicad_pcb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]
2026-03-30 v3 dev r3 candidate
    [bom.csv, dev-board.kicad_pcb, positions.csv]
2026-04-02 v3 dev r3 candidate2
    [S3_peripheral.kicad_sch, bom.csv, dev-board.kicad_pcb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]
2026-04-02 update board image
2026-04-02 add schematics
